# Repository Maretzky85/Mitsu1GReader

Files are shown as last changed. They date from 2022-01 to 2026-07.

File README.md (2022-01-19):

# Mitsu1GReader

### Quick and dirty playground to learn C++ and Arduino.
### For educational purposes only

## Description
As my hobby om mine, i do lots of stuff related to older mitsubishi cars, and ECUs.
This is my attempt to make my life easier while performing diagnostics on older (1988 - 1994) mitsubishi ecus.

My goal is to create diagnostic bench for those ECUs, and as a part of this project is to create device that is stand alone and have ability to check if ecu is performing as expected (is able to communicate and reads all data from sensors).

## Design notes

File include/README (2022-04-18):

;******************************************************************
;*
;* OBD interface queries, commands
;*
;* Codes from $00 to $3d: Regular queries, return the value of the
;* variables showed in obdTable located below,
;* see each variable definition... First value in table
;* correspond to obd query code $00, increases by 1
;* for each table value
;*
;* Codes from $3e to $3f: Converted to $3d, see that obd code
;*
;* Codes from $40 to $c9: Returns what is stored in that ram address
;*
;* Codes from $ca to $ca:: Erase all fault codes and returns $00 if
;* engine not rotating. If engine is rotating, all
;* actuators/injector commands are reset and $ff
;* is returned.
;*
;* Codes from $cb to $f0: Returns what is stored in that ram address
;*
;* Codes from $f1 to $fc: Injector/actuators commands, returns $ff if
;* successfull
;*
;* $f1: Activate boost control solenoid
;* $f2: Unused in code
;* $f3: Activate egr solemoid
;* $f4: Activate fuel pressure solenoid
;* $f5: Activate purge solenoid
;* $f6: Turn on fuel pump
;* $f7: Disable injector #6 (inoperative in code)
;* $f8: Disable injector #5 (inoperative in code)
;* $f9: Disable injector #4
;* $fa: Disable injector #3
;* $fb: Disable injector #2
;* $fc: Disable injector #1
;*
;* Codes from $f1 to $ff: Special queries
;*
;* $fd: Serial link test, returns $b5 (E931) or $b7 (E932)
;* $fe: resistor strapping low word from t_strap3
;* $ff: resistor strapping high word from t_strap3
;*
;******************************************************************

This directory is intended for project header files.

A header file is a file containing C declarations and macro definitions
to be shared between several project source files. You request the use of a
header file in your project source file (C, C++, etc) located in `src` folder
by including it, with the C preprocessing directive `#include'.

```src/main.c

#include "header.h"

int main (void)
{
 ...
}
```

Including a header file produces the same results as copying the header file
into each source file that needs it. Such copying would be time-consuming
and error-prone. With a header file, the related declarations appear
in only one place. If they need to be changed, they can be changed in one
place, and programs that include the header file will automatically use the
new version when next recompiled. The header file eliminates the labor of
finding and changing all the copies as well as the risk that a failure to
find one copy will result in inconsistencies within a program.

In C, the usual convention is to give header files names that end with `.h'.
It is most portable to use only letters, digits, dashes, and underscores in
header file names, and at most one dot.

Read more about using header files in official GCC documentation:

* Include Syntax
* Include Operation
* Once-Only Headers
* Computed Includes

https://gcc.gnu.org/onlinedocs/cpp/Header-Files.html

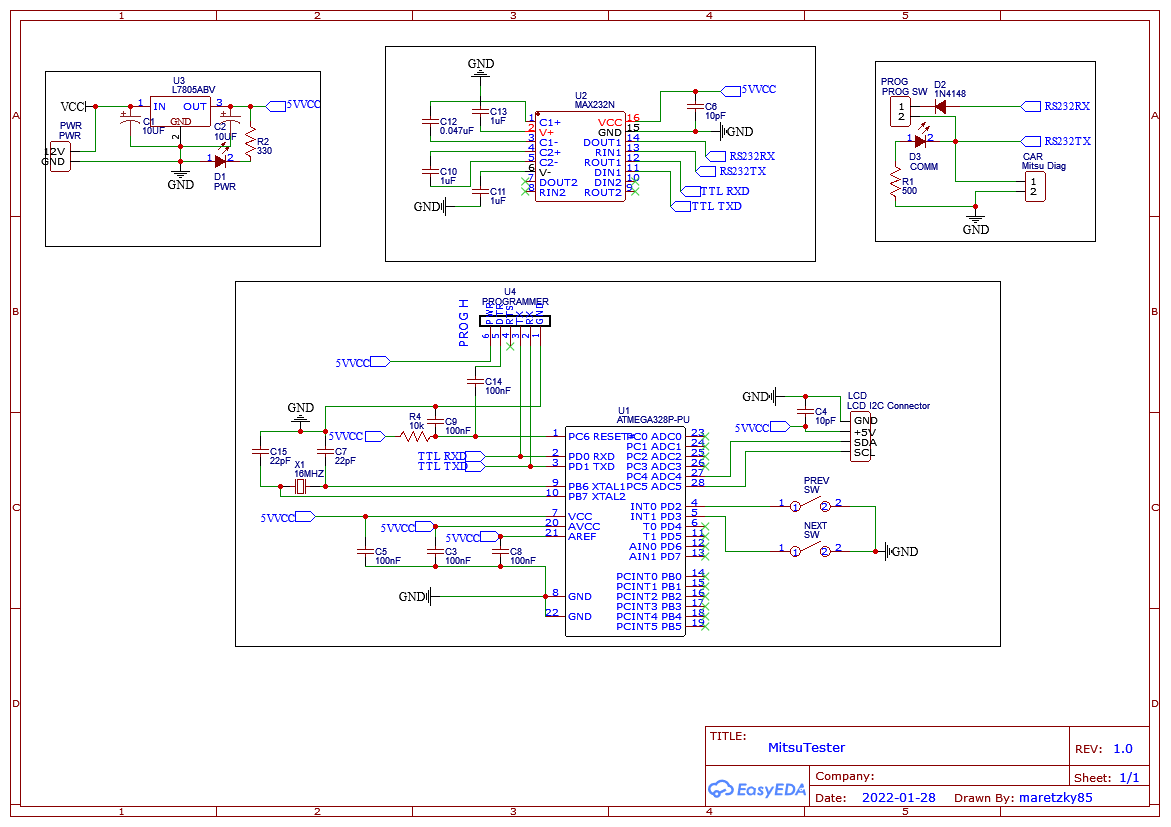
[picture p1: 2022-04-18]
assets/Schematic.png

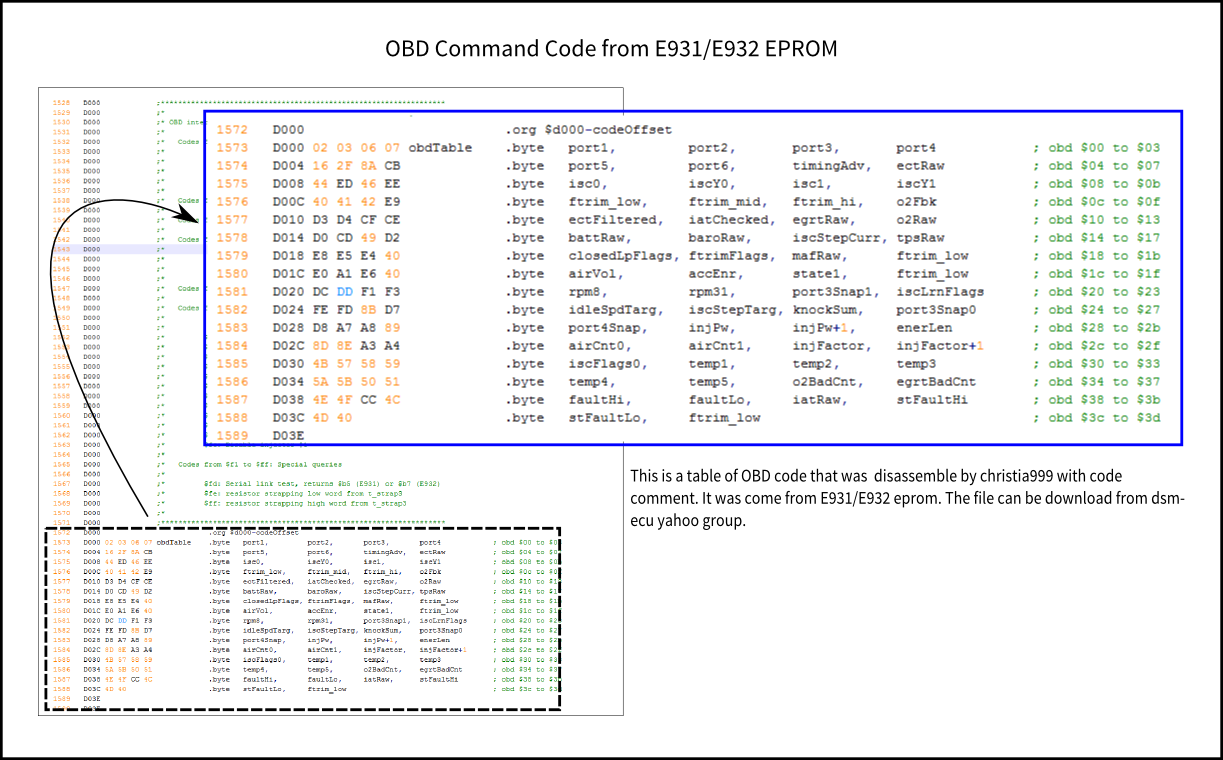
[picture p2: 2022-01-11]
assets/E392 OBD Code 1.png

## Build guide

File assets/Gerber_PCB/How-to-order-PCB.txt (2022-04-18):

How to Order PCB

Please refer to:
https://docs.easyeda.com/en/PCB/Order-PCB

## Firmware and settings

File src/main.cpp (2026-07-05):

#include <Arduino.h>
#include <buttons.h>
#include <commands.h>
#include <lcd.h>
#include <dataReader.h>
#include <dtcReader.h>
#include <ecuInfo.h>
#include <switches.h>

#define DATA_READER 0
#define SW_READER 1
#define DTC_READER 2
#define COMMANDS 3
#define MAX_STATE 4

const char WELCOME[] PROGMEM = "MitsuTester";

int state[4]
        {
                DATA_READER,
                SW_READER,
                DTC_READER,
                COMMANDS
        };

int currentState = DATA_READER;

void setup() {
    lcdStart();
    printHeader(WELCOME);
    delay(500);
    pinMode(prevButtonPin, INPUT_PULLUP);
    pinMode(nextButtonPin, INPUT_PULLUP);
    Serial.begin(1953);
    showEcuInfo();
}

void updateState() {
    updateButtonsState();
    if (buttonState == LONG_NEXT) {
        redraw = true;
        currentState++;
        clearScreen();
        if (currentState == MAX_STATE) {
            currentState = 0;
        }
    }
    if (buttonState == LONG_PREVIOUS) {
        redraw = true;
        clearScreen();
        if (currentState == 0) {
            currentState = sizeof(state) / sizeof(*state) - 1;
        } else {
            currentState--;
        }
    }

}

void loop() {
    updateState();
    updateStatus();
    switch (currentState) {
        case DATA_READER:
            dataReader();
            break;
        case DTC_READER:
            dtcReader();
            break;
        case COMMANDS:
            commands_proc();
            break;
        case SW_READER:
            run_switches_routine();
            break;
        default:
            break;
    }
    redraw = false;
}

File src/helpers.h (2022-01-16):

const char *EMPTY[] = {""};
struct request
{
    int addr;
    int parser;
    char name[14];
    char unit[5];
};

enum requests_addr
{
    SWITCHES = 0x02,
    BATT_VOLTAGE = 0x14,
    ACC_ENRICH = 0x1D,
    COOLANT_TEMP = 0x07,
    ENGINE_SPEED = 0x21,
    FUEL_TRIM_LOW = 0x0C,
    FUEL_TRIM_MID = 0x0D,
    FUEL_TRIM_HIGH = 0x0E,
    INJECTOR_PULSE = 0x29,
    OXYGEN_FEEDBACK_TRIM = 0x0F,
    OXYGEN_SENSOR = 0x13,
    TPS = 0x17,
    AIR_FLOW_HZ = 0x1A,
    AIR_TEMP = 0x3A,
    AIR_VOLUME = 0x2C,
    BARO_SENSOR = 0x15,
    ISC_STEPS = 0x16,
    KNOCK_SUM = 0x26,
    TIMING_ADVANCE = 0x06,
    EGR_TEMP = 0x12,
    MAX_REQUEST
};

#define MASK_TDC 4
#define MASK_PS 8
#define MASK_AC_SW 16
#define MASK_PARK_N 32
#define MASK_IDDLE_SW 128

#define P_RAW 0
#define P_12V 1
#define P_FEEDBACK_TRIM 2
#define P_ZERO_ONE 3
#define P_PERCENT 4
#define P_RPM 5
#define P_TIMING_ADVANCE 6
#define P_COOLING_TEMP 7
#define P_INJ_PULSE 8
#define P_AIR_FLOW_HZ 9
#define P_AIR_TEMP 10
#define P_BARO 11
#define P_EGR_TEMP 12
#define P_TDC 13
#define P_PS 14
#define P_AC_SW 15
#define P_PARK_NEUTRAL 16
#define P_IDDLE_SW 17

char buffer[14] = "";

request requests[] = {
    // {SWITCHES, P_TDC, "TDC", " "},
    // {SWITCHES, P_PS, "Power Steering", " "},
    // {SWITCHES, P_AC_SW, "A/C Switch", " "},
    // {SWITCHES, P_PARK_NEUTRAL, "PARK/NEUTRAL", " "},
    // {SWITCHES, P_IDDLE_SW, "Iddle switch", " "}, //TODO move to different routine
    {BATT_VOLTAGE, P_12V, "Batt", "V"},
    {ACC_ENRICH, P_PERCENT, "Acc enrich", "%"},
    {COOLANT_TEMP, P_COOLING_TEMP, "Coolant", "C"},
    {ENGINE_SPEED, P_RPM, "Engine Speed", "RPM"},
    {FUEL_TRIM_LOW, P_FEEDBACK_TRIM, "Fuel Trim Low", "%"},
    {FUEL_TRIM_MID, P_FEEDBACK_TRIM, "Fuel Trim Mid", "%"},
    {FUEL_TRIM_HIGH, P_FEEDBACK_TRIM, "Fuel Trim Hgh", "%"},
    {INJECTOR_PULSE, P_INJ_PULSE, "Inj Pulse", "ms"},
    {OXYGEN_FEEDBACK_TRIM, P_FEEDBACK_TRIM, "Oxygen Fdbck", "%"},
    {OXYGEN_SENSOR, P_ZERO_ONE, "Oxygen Sens", "V"},
    {TPS, P_PERCENT, "TPS", "%"},
    {AIR_FLOW_HZ, P_AIR_FLOW_HZ, "Air Flow", "Hz"},
    {AIR_TEMP, P_AIR_TEMP, "Air Temp", "C"},
    {AIR_VOLUME, P_RAW, "Air Volume", " "},
    {BARO_SENSOR, P_BARO, "Baro Sensor", "Hpa"},
    {ISC_STEPS, P_RAW, "ISC steps", "Step"},
    {KNOCK_SUM, P_RAW, "Knock Sum", " "},
    {TIMING_ADVANCE, P_TIMING_ADVANCE, "Ign Advance", "deg"},
    {EGR_TEMP, P_EGR_TEMP, "Egr Temp", "C"}};

//TODO do not use string, and move to different file
// bool parseWithMask(int rawValue, int mask)
// {
//     return (rawValue & mask) == mask;
// }

void parseEgrTEmp(int rawValue, char* unit)
{
    int result = -2.14 * rawValue + 314;
    sprintf(buffer, "%4s%3d %-6s", *EMPTY, result, unit);
}

void parseAirTemp(int rawValue, char* unit)
{
    // return -0.81 * rawValue + 153;
    int result = -0.94 * rawValue + 181;
    sprintf(buffer, "%4s%3d %-6s", *EMPTY, result, unit);
}

void parseAirFlowHz(int rawValue, char* unit)
{
    int result = 6.29 * rawValue;
    sprintf(buffer, "%4s%4d %-5s", *EMPTY, result, unit);
}

void parseTimingAdvance(int rawValue, char* unit)
{
    int result = rawValue - 10;
    sprintf(buffer, "%4s%2d %-7s", *EMPTY, result, unit);
}

void parseToTwelve(int &rawValue, char* unit)
{
    float result = rawValue * 0.0733f;
    char tmpInt1 = result;
    float tmpFrac = result - tmpInt1;
    char tmpInt2 = trunc(tmpFrac * 100);
    sprintf(buffer, "%3s%-2d.%-2d %-5s", *EMPTY, tmpInt1, tmpInt2, unit);
};

void parseToPercent(int rawValue, char* unit)
{
    int result = 100 * rawValue / 255;
    sprintf(buffer, "%5s%3d %-5s", *EMPTY, result, unit);
}

void parseFeedbackTrim(int rawValue, char* unit)
{
    int result = rawValue * 0.78;
    sprintf(buffer, "%5s%3d %-5s", *EMPTY, result, unit);
}

void parseZeroOne(int rawValue, char* unit)
{
    float result = rawValue * 0.0195f;
    char tmpInt1 = result;
    float tmpFrac = result - tmpInt1;
    char tmpInt2 = trunc(tmpFrac * 100);
    sprintf(buffer, "%3s%2d.%-2d %-5s", *EMPTY, tmpInt1, tmpInt2, unit);
}

void parseRPM(int rawValue, char* unit)
{
    int result = rawValue * 31.25;
    sprintf(buffer, "%4s%4d %-5s", *EMPTY, result, unit);
}

void parseCoolant(int rawValue, char* unit)
{
    int result = -0.81 * rawValue + 153;
    sprintf(buffer, "%5s%3d %-5s", *EMPTY, result, unit);
}

void parseInjPulse(int rawValue, char* unit)
{
    int result = 0.256 * rawValue;
    sprintf(buffer, "%6s%2d %-5s", *EMPTY, result, unit);
}

void parseBaro(int rawValue, char* unit)
{
    int result = 0.00486 * rawValue * 1000;
    sprintf(buffer, "%4s%4d %-5s", *EMPTY, result, unit);
}

char *parseData(int &data, request * requestData)
{
    int parser = requestData->parser;
    switch (parser)
    {
    case P_RAW:
        sprintf(buffer, "%5s%3d%6s", "", data, requestData->unit);
        break;
    case P_12V:
        parseToTwelve(data, requestData->unit);
        break;
    case P_PERCENT:
        parseToPercent(data, requestData->unit);
        break;
    case P_FEEDBACK_TRIM:
        parseFeedbackTrim(data, requestData->unit);
        break;
    case P_ZERO_ONE:
       parseZeroOne(data, requestData->unit);
        break;
    case P_RPM:
        parseRPM(data, requestData->unit);
        break;
    case P_TIMING_ADVANCE:
        parseTimingAdvance(data, requestData->unit);
        break;
    case P_COOLING_TEMP:
        parseCoolant(data, requestData->unit);
        break;
    case P_INJ_PULSE:
        parseInjPulse(data, requestData->unit);
        break;
    case P_AIR_FLOW_HZ:
        parseAirFlowHz(data, requestData->unit);
        break;
    case P_AIR_TEMP:
        parseAirTemp(data, requestData->unit);
        break;
    case P_BARO:
        parseBaro(data, requestData->unit);
        break;
    case P_EGR_TEMP:
        parseEgrTEmp(data, requestData->unit);
        break;

    // case P_TDC:
    //     return String(parseWithMask(data, MASK_TDC));
    //     break;
    // case P_PS:
    //     return String(parseWithMask(data, MASK_PS));
    //     break;
    // case P_AC_SW:
    //     return String(parseWithMask(data, MASK_AC_SW));
    //     break;
    // case P_PARK_NEUTRAL:
    //     return String(parseWithMask(data, MASK_PARK_N));
    //     break;
    // case P_IDDLE_SW:
    //     return String(parseWithMask(data, MASK_IDDLE_SW));
    //     break;
    default:
        sprintf(buffer, "%11s%3d", "", data);
        break;
    }
    return buffer;
};

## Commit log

2022-01-07 add button
2022-01-08 add switches to requests
2022-01-08 cleanup & buttons
2022-01-11 fix: change request adresses to hex
    [helpers.h]
2022-01-11 refactor, add comm routine, remove String from error printing update dtcReader for new comm routine
2022-01-11 move buttons state to buttons.h
2022-01-12 add state to dtc, add button routine
2022-01-22 add connection status indicator, remove error type checks
    [communication.cpp, main.cpp]
2022-01-22 add switches 4 row support
2022-01-22 add PREV support for switches
2022-01-29 change switches input to internal pullup
2022-04-18 add assets
    [Drill_NPTH_Through.DRL, Drill_PTH_Through.DRL, Gerber_BoardOutlineLayer.GKO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]
2026-07-05 fix scalings against MH6111 ROM ground truth
    Cross-checked every parser against the disassembled E931/E932 ROM
    (mh6111_project/source/standard_E932_E931_source.asm). Replaced the
    linear coolant/IAT formulas with the actual thermistor lookup tables
    from the Mitsu MMCD service curve, corrected the EGR temp formula
    (ROM stores degF not degC), fixed the fuel trim scale (0.78% per LSB
    with $80 = 100%), extended injPw to a proper 16-bit us read, and
    corrected the SCI baud to 1953.
    - switch coolant/IAT queries to filtered variants ($10/$11)
    - read injPw as 16-bit via $29:$2A for 1us resolution
    - move parser enum to header so dataReader can dispatch on it
    - document the MH6111 diagnostic protocol i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
    [main.cpp]
2026-07-05 identify unlabeled solenoids, drop dangerous DTC-clear commands, fix switches
    Solenoid labels: $F1 = boost/wastegate, $F3 = EGR, $F4 = fuel-pressure
    solenoid. $F2 has no downstream reference in E931 (dead bit in this ROM).
    INJ5/INJ6 rows kept for cross-ROM consistency though the ECU silently
    discards them on 4-cyl.
    DTC clear: previous list also sent $7E, $FA, $FC alongside the correct
    $CA. Only $CA clears faults; $FA/$FC actively kill an injector for 6s
    if the ECU accepts them. Reduced to {$CA}.
    Switches: removed 7 rows with mask=0x00 that always read ON. Added
    fuel-pump-relay ($10 on port1) and key-in-start ($40 on port3) rows
    that were previously labeled UNK. Cited ROM line refs inline.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
    [commands.cpp]
2026-07-05 add octane, knock-decay and closed-loop-flags via direct RAM peek
    The MH6111 responds to obdCodes in the range \$40..\$F0 (excluding \$CA)
    by returning the byte at RAM address = code. That opens 177 read-only
    peek addresses beyond what the obdTable covers. Adding the three most
    useful for diagnosing this car's persistent knock-sensor error:
    - Octane (\$52): running ignition-timing octane counter. Decrements when
    the knock routine flags noise, increments while clean. Best real-time
    proxy for whether the ECU currently thinks it is knocking.
    - KnockDecay (\$8C): T200s_knock timer; non-zero means the ECU is
    actively pulling timing right now.
    - CL Flags (\$E8): closedLpFlags bitfield -- bi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
2026-07-05 add boot-time ECU Info splash
    Sends the three ROM-fingerprint queries ($FD, $FE, $FF) once at startup
    and displays the result for ~3 seconds before entering the main loop.
    The $FD dispatch was disassembled for every ROM in mh6111_project/roms/,
    giving a compact 7-entry lookup table that maps the response byte to
    the ROM family: E742=\$36, E766=\$4F, E799=\$61, E931=\$B5, E932=\$B7,
    E935=\$14, E44228B5=\$46, pxs_rom=\$B5 (E931-derived).
    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
2026-07-05 make ECU info splash market-agnostic
    The DSM slot taxonomy (Fwd/Awd x Fed/Cal) that the E931 source uses to
    label its 4 t_strap3 slots is US-market specific. EDM Galant VR4 and
    JDM (901/902A) ROMs almost certainly reuse those 4 slots for different
    market variants (LHD/RHD, JDM/export, etc), so hardcoding US slot
    names in the tool would mislabel non-US ECUs.
    Now displays:
    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
2026-07-05 platformio: split into uno, nano_old, nano_new envs
    The original board = uno config still works for the custom PCB (Uno-style
    optiboot @ 115200) so that stays as env:uno and env:nanoatmega328 alias.
    Added env:nano_old for classic Nano stk500v1 @ 57600 and env:nano_new
    for optiboot Nano @ 115200. Shared config lifted into [env].
2026-07-05 fix OOB write in ECU info splash and swapped actuator labels
    The lcd helpers' internal dedup arrays (lastResults[3], resultBuffers[3])
    have 3 slots even though LCD_ROWS = 4. Every existing screen respects
    this by looping i in 0..2 (LCD_ROWS-1 with an offset). The ECU info
    splash was written with row indices 1, 2, 3 -- writing to
    lastResults[3] via String::operator=() corrupted adjacent globals,
    which surfaced as freezes/resets when later screens (actuator/commands)
    did more String work. Shift indices down to 0, 1, 2 to match convention.
    Also fix U1/U4 label swap: U1 = $F4 -> mask $04 = FPS (not boost), and
    U4 = $F1 -> mask $20 = boost (not FPS). Pressing "Boost" was actually
    firing FPS and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
    [commands.cpp]
2026-07-05 decode closedLpFlags into human-readable status string
    The raw hex byte at closedLpFlags (\$E8) was displayed as "0x84h" which
    tells you nothing at a glance. Replace with a 7-char decoded status:
    Ri/Le CLok -- rich or lean, closed-loop conditions met
    Ri/Le airH -- rich or lean, airflow above CL threshold (open loop)
    Ri/Le o2!! -- o2 sensor flagged bad (didn't switch in timeout)
    Ri/Le open -- open loop, no specific fault indicated
    Bits decoded from ROM annotations at line 1115-1122 (bit 7 = rich/lean,
    bit 6 = o2 bad, bit 1 = closed-loop candidate, bit 0 = airflow high).
    Bits 2-5 are undocumented in the source and not exposed here.
    Note: whether the ECU is actually IN closed loo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
2026-07-05 add state1 decode + full-row LCD helper for splash text
    Two related fixes:
    1. Splash text was wrapping past the LCD edge because printResult() writes
    at column 12 (right side, 8-char window) -- the splash strings are
    12-15 chars each. Added printFullRow(row, text) which writes at
    column 0 with LCD_COLS padding, bypassing the dedup buffers used by
    the standard printResult(). ECU info splash now uses it for all four
    rows and text lands correctly.
    2. state1 ($1E) exposed as a new sensor entry with human-readable decode:
    "<eng> <loop>" where eng is one of OFF/cnk/cut/rev/cas/run and loop
    is CL or OL. This is the actual closed-loop-active latch (bit 7);
    closedLpFlags onl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
2026-07-05 fix splash blank and commands-screen crash after DTC visit
    Three separate bugs, all surfacing after the previous commit:
    1. printFullRow's snprintf("%-*s", ...) silently produced empty
    strings on builds using avr-libc's minimal printf (no '*' width
    support), so ECU-Info splash rows 1-3 stayed blank. Replaced with
    manual copy-and-pad.
    2. clearScreen() called lcd.clear() but left the dedup caches intact,
    so the next printHeader() with the same PROGMEM pointer was
    skipped and the header row never redrew. clearScreen() now
    invalidates lastPrintedHeader / lastPrintedStatus /
    lastPrintedResultsName[] and empties lastResultPrinted /
    lastResults[].
    3. dtcReader's printFirs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
2026-07-05 switches: continue instead of return on COMM_ERR
    Early return on the first ECU comm error aborted the whole row loop
    so only row 0's name was drawn. This was masked previously because
    clearScreen() didn't invalidate the dedup cache -- stale content from
    the last screen made rows 1-2 look populated. With proper cache
    clearing (prev commit), the abort is visible: switches screen shows
    only one name without ECU. Use continue so all names print; value
    column stays blank for rows that couldn't be read.
